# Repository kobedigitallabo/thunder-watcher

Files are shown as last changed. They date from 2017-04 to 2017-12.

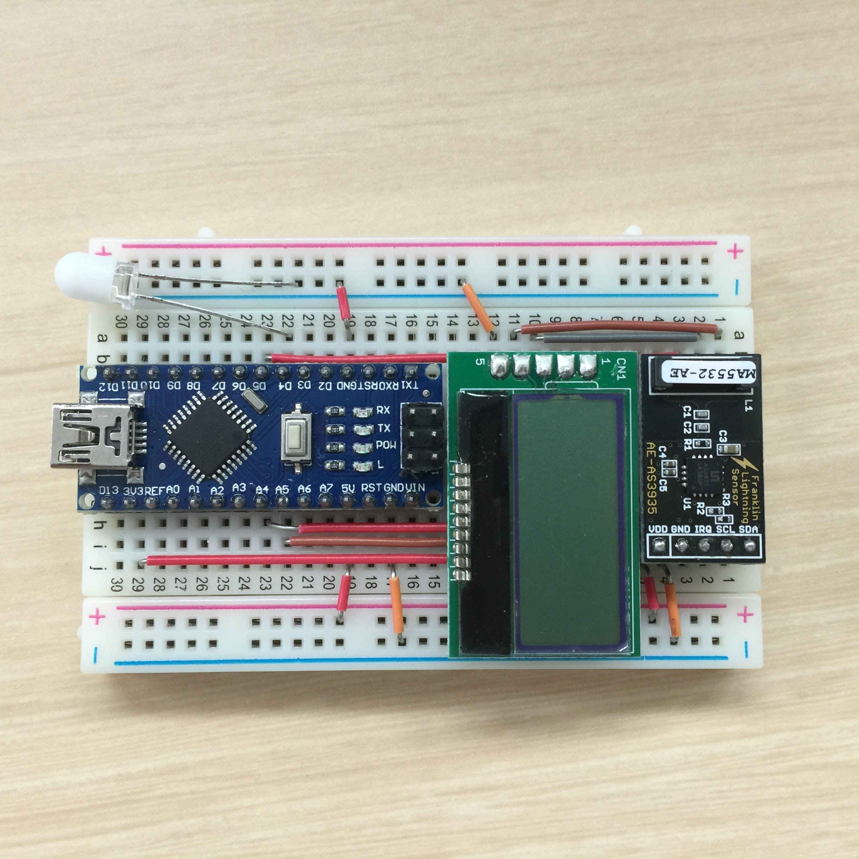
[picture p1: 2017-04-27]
document/protoboard2.jpg

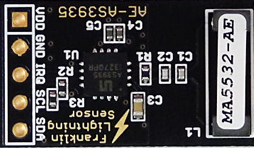
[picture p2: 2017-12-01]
document/AS3935.png

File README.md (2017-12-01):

The Thunder Watcher.
====
This device can sense the approach of lightning within several dozen kilometers, and make an alert to hide.
- Early warning indication of lightning storm activity within a 40km range.
- Provide you distance estimation from a overhead thunderstorm.
- Detects both cloud-to-ground and intra-cloud (cloud-to-cloud) flashes.
- The intelligent algorithm provides for false disturber rejection.

pic1.png (344.1 kB)

# Description
The Thunder Watcher  is a programmable Wearable Device that detects the presence and approach of potentially hazardous lightning activity in the vicinity.  
It detects intra-cloud activity as well as cloud to ground ashes, often enabling risk to be evaluated for approaching storms.   
The AS3935 IC detects lightning activity as it approaches from up to 40 km away, which provides a much longer distance for lightning warning.  

pic2.png (367.2 kB)

# Demo
ezgif.com-video-to-gif.gif (2.8 MB)

# Requirement
* [ Arduino IDE 1.6.13](https://www.arduino.cc/en/main/OldSoftwareReleases)
* [FreqCounter Library](http://interface.khm.de/index.php/lab/interfaces-advanced/arduino-frequency-counter-library/)
* [ST7032 Library](https://github.com/tomozh/arduino_ST7032)

# Usage
1. Turn on the power switch.(Initialization is started.) 
1. You have to wait for a thunderstorm. 
1. When a thundercloud is detected, the LED will light up.
And the distance to the thundercloud is displayed on the LCD display. 
1. If thunderclouds are near, evacuate to a safe place.

# What do we need
* [an Arduino nano board](https://www.amazon.com/HiLetgo-ATmega328P-Controller-Development-Unsoldered/dp/B01DLIJQA2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)

* [a Franklin Lightning Sensor (AS3935)](http://akizukidenshi.com/catalog/g/gK-08685/)

* [2x Round female pin header [5x1, 2.54mm]](https://www.amazon.com/Break-Away-Female-Headers-Machine/dp/B004G553U2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)
* 2x Male pin header [7x1, 2.54mm]
* [a  7x7 Perf Board  [2.54mm]](https://www.amazon.com/a14060500ux0490-Universal-Prototype-Solderable-Circuit/dp/B010XA3NZK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)
*  a 6x4  Perf Board  [2.54mm]
* [a Tinned Copper Wire](https://www.amazon.com/dp/B000IJU260/ref=biss_dp_t_asn)
* [a Plastic Battery Holder for 2 x 3V CR2032 Coin Button Cell](https://www.amazon.com/Copapa-Plastic-Battery-Holder-CR2032/dp/B01N0L9JFU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)
* Watch Bands
* an LED
* [an LED Lens, Diffused Beam](http://cy.rsdelivers.com/product/asahi-rubber/a-48068l-kc/asahi-rubber-a-48068l-kc-led-lens-diffused-beam/5017104)
* [a 150 Ohm Resistor, 1/4 W](https://www.amazon.com/E-Projects-100EP514150R-150-Resistors-Pack/dp/B0185FGNI4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)
* [an Empty electronic lighter](https://www.amazon.com/Refillable-Cigarette-Lighter-Flashlight-Quantity/dp/B009Z2R1U6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)

image.png (4.1 MB)

#  Tools You Need
* Soldering iron
* Soldering iron stand
* Solder
* Lead Nippers
* Needle Nose Pliers
* Reverse Action Tweezers
* Utility Knife
* Stainless Steel Ruler
* Glue gun

image.png (4.1 MB)

# The circuit
ThunderWatcher_circuit.png (492.4 kB)

# Install
## Importing a FreqCounter Library
[Lab3 \- Laboratory for Experimental Computer Science](http://interface.khm.de/index.php/lab/interfaces-advanced/arduino-frequency-counter-library/)

1. In the Arduino IDE, navigate to Sketch > Include Library. 
1. At the top of the drop down list, select the option to "Add .ZIP Library''.
1. You will be prompted to select the library you would like to add.
1. Return to the Sketch > Import Library menu. You should now see the library at the bottom of the drop-down menu.
1. It is ready to be used in your sketch. The zip file will have been expanded in the libraries folder in your Arduino sketches directory.

## Importing a ST7032 Library
[tomozh/arduino\_ST7032\- Arduino Liquid Crystal compatible library](https://github.com/tomozh/arduino_ST7032)

1. When you are on arduino_ST7032 project page, you press the 'Download ZIP' button which is located under the "Clone or Download" drop down.
1. This allows you to download the most recent version of the code as a zip archive.
image.png (23.1 kB)
1. Down list, select the option to "Add .ZIP Library''.
You will be prompted to select the library you would like to add.
1. Return to the Sketch > Import Library menu. You should now see the library at the bottom of the drop-down menu. 
1. It is ready to be used in your sketch. The zip file will have been expanded in the libraries folder in your Arduino sketches directory.

# How to make
More info is recorded in the "HowToMake-Desc.md" file.  
[HowTo/arduino/How to make  Thunder Watcher.](/HowToMake-Desc.md)

# Contribution
1. Fork it (http://github.com/kobedigitallabo/thunder-watcher )
2. Create your feature branch (git checkout -b my-new-feature)
3. Commit your changes (git commit -am 'Add some feature')
4. Push to the branch (git push origin my-new-feature)
5. Create a new Pull Request

# Licence
[MIT](/LICENSE.txt)

# Author
[kobedigitallabo](https://github.com/kobedigitallabo)

[haru-kdl](https://github.com/haru-kdl)

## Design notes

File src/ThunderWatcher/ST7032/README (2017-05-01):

ST7032 - Arduino LiquidCrystal compatible library
http://ore-kb.net/archives/195

-------------------------------------------------------------
 概要
-------------------------------------------------------------

コントローラに ST7032i を使った I2C LCD ディスプレイの
Arduino ライブラリです。
LiquidCrystal ライブラリのソースを元に作成しています。
LiquidCrystal ライブラリのメンバ関数と互換性があるため、
クラスを差し替えるだけで使用できます。

動作確認済み

    SB1602B             Strawberry Linux
    SB0802G             Strawberry Linux
    AQM0802A-RN-GBW     秋月電子通商

動作すると思われるもの

    SB1602E             Strawberry Linux
    LCD16X2-I2C         aitendo
    SPLC792-I2C-M       aitendo
    16X2-SPLC792-I2C    aitendo

-------------------------------------------------------------
 更新履歴
-------------------------------------------------------------

2014.10.13 コントラスト値のbit7がBONビットに影響する不具合を修正
2014.08.23 コンストラクタでI2Cアドレスを設定可能にした
2013.05.21 1st release

-------------------------------------------------------------
 ライセンス
-------------------------------------------------------------

作成者：
tomozh (tomozh@gmail.com)

ライセンス形態：
MIT

-------------------------------------------------------------
 使用方法
-------------------------------------------------------------

1) モジュールと Arduino を以下のように接続します

 ------------------------
  Arduino        ST7032
 ------------------------
  3.3V    --+-- VDD
            +-- -RES
  A4(SDA) --*-- SDA
  A5(SCL) --*-- SCL
  GND     ----- GND
  
  *... 10Kohm pull-up
 ------------------------

LCDを確実にリセットしたい場合は、RST 端子を Arduino の
空き端子で制御してください。(Low:リセット)
 
2) ST7032 フォルダを Arduino の libraries フォルダにコピーします

ST7032 独自のメンバ関数は以下の2種類です。

    コンストラクタ
       ST7032 lcd(int i2c_addr);
            i2c_addr: スレーブアドレス
            コンストラクタ引数を省略した場合は 0x3E

    コントラスト設定
        void setContrast(uint8_t cont)
            cont: コントラスト値 (0～63)
    
    アイコン表示 (※アイコン表示機能の無いLCDは無効)
        void setIcon(uint8_t addr, uint8_t bit)
            addr : アイコンアドレス (0～15)
            bit  : アイコン表示ビット (0x00～0x1F)

簡単な使い方

#include <Wire.h>
#include <ST7032.h>

ST7032 lcd;

lcd.setContrast(30);            // コントラスト設定
lcd.print("hello, world!");

スレーブアドレスを指定する場合

ST7032 lcd(0x3E);

-------------------------------------------------------------
 ファイル構成
-------------------------------------------------------------

ST7032\
    keywords.txt
    ST7032.cpp              ST7032 ライブラリ
    ST7032.h                ST7032 ライブラリ
    examples\
        Icon                Strawberry Linux SB1602B 用アイコン表示デモ
        Autoscroll          (*)
        Blink               (*)
        Cursor              (*)
        CustomCharacter     (*)
        Display             (*)
        HelloWorld          (*)
        Scroll              (*)
        SerialDisplay       (*)
        setCursor           (*)
        TextDirection       (*)

        (*)…LiquidCrystal liblary を ST032 用に改変

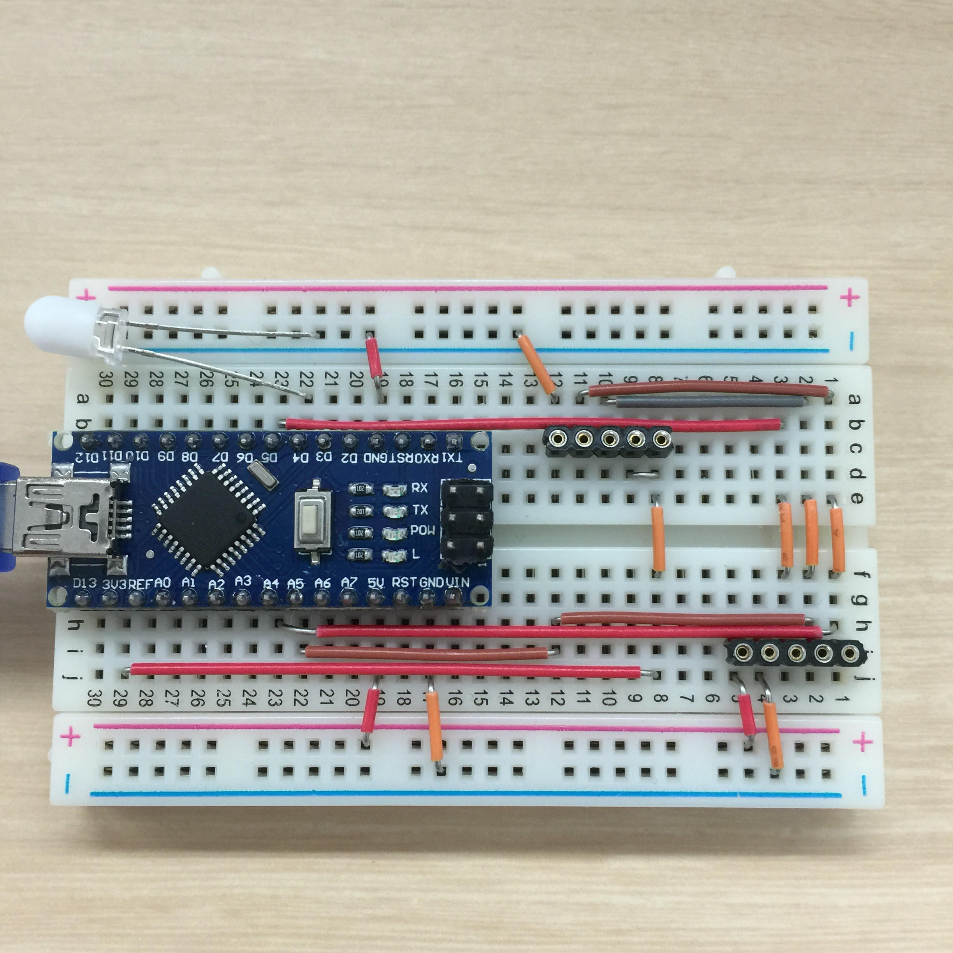
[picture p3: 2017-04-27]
document/protoboard1.jpg

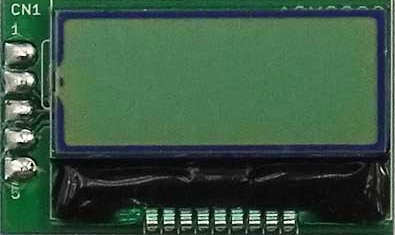
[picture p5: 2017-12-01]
document/AQM0802.png

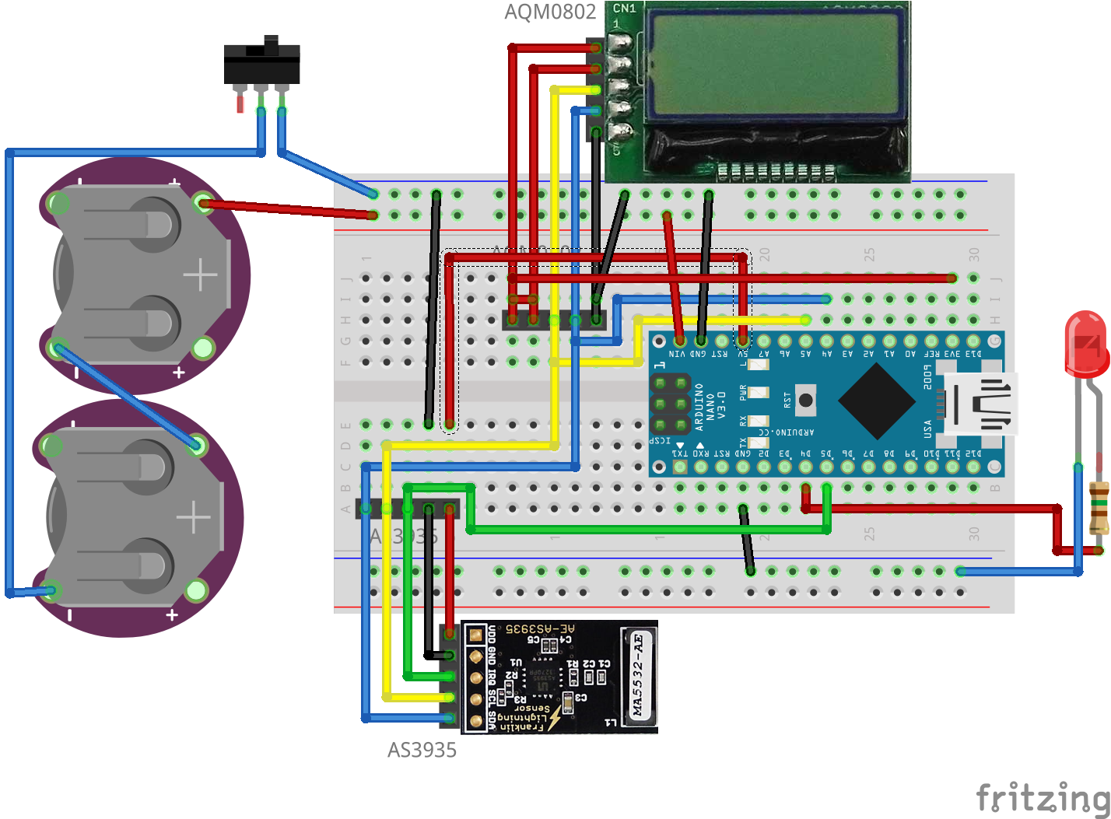
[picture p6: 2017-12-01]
document/ThunderWatcher_circuit.png

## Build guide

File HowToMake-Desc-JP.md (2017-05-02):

# Thunder Watcher 作成手順
## センサとLCDシールドを作成します。
まずは、センサとLCDシールドを作成します。

## ユニバーサル基板をカットする
2.54mm ピッチのユニバーサル基板をカットして、7x7 と 6x4  の板を準備します。  

スクリーンショット 2017-04-27 16.41.00.png (344.5 kB)

6x4 の基板は端の穴を半分残してカットします。

スクリーンショット 2017-04-27 16.42.33.png (225.3 kB)

## 7x7 穴のユニバーサル基板 にピンヘッダ(オス)を取り付ける
 
7x1  ピンヘッダ(オス) [2.54mm] を用意します。  
端子が長い側を銅パッド面となるように差し込みます。  
各ヘッダの一つのピンをはんだ付けします。  
これらのピンをはんだ付けした状態で、ヘッダの位置を確認してみてください。   
各ヘッダーは、基板に対して90°の角度となっている事が大切です。  
問題なければ残りのピンを全てはんだ付けします。 

スクリーンショット 2017-04-27 16.54.18.png (450.3 kB)

スクリーンショット 2017-04-27 16.55.30.png (292.4 kB)
スクリーンショット 2017-04-27 16.56.36.png (329.8 kB)

ピン番号は下図の通りです。
  
スクリーンショット 2017-04-27 16.56.36.png (329.8 kB)

## スズメッキ線をピンヘッダにはんだ付けする
スズメッキ線を14番ピンの近くの穴から通します。  
それを14番ピンにはんだ付けしてください。



基板を裏返し、下図の通りに折り曲げます。
余ったスズメッキ線は切断します。

image.png (121.2 kB)

下図の通りに折り曲げた場合、Arduinoのボタンと干渉してしまいますので、注意してください。

image.png (158.6 kB)

下図の通りに1番ピンにスズメッキ線をはんだ付けします。  

image.png (100.7 kB)

下図の通りに折り曲げます。

image.png (71.6 kB)

下図の通りに2番ピンにスズメッキ線をはんだ付けします。

image.png (90.6 kB)

下図の通りに折り曲げます。  

image.png (73.8 kB)

Pスズメッキ線を5番ピンの近くの穴から通します。  
それを5番ピンにはんだ付けしてください。  

png

png

下図の通りに折り曲げます。  
 
png

## 丸ピンヘッダ(メス)をはんだ付けする

7番ピンの近くの丸ピンヘッダ(メス)をはんだ付けします。  

Clip8.m4v 2017-04-27 17-49-46.png (84.8 kB)

裏返して、5番ピンからのびるスズメッキ線と丸ピンをはんだ付けします。  

Clip8.m4v 2017-04-27 17-52-48.png (72.0 kB)

 次に、14番ピンからのびるスズメッキ線と丸ピン(真ん中のピン)をはんだ付けします。  

Clip12.m4v 2017-04-27 20-52-08.png (347.5 kB)



1番ピンと2番ピンからのびるスズメッキ線と交差する丸ピン (右端とその隣) をはんだ付けします。





## 6x4 穴のユニバーサル基板にはんだ付けする
6x4 の基板を7x7 の基板に下図の通りにはんだ付けします。 
下図の通りに位置を合わせます。

 
下図の通りにはんだ付けします。  



1つのピンにハンダ付けします。  
高さの位置はピンヘッダの先頭に合わせてはんだ付けします。  
このピンをはんだ付けした状態で、ヘッダーの位置合わせをテストしてください。  


残りのピンも全てはんだ付けします。  



## 6x4の基板に丸ピンヘッダ(メス)をはんだ付けする

一番端のピンを下図の通りにはんだ付けします。  
Clip11.m4v 2017-04-27 18-24-50.png (103.6 kB)

下図の通りに、1番ピンをL字にスズメッキ線をはんだ付けします。  

Clip11.m4v 2017-04-27 18-28-19.png (349.8 kB)

下図の通りに、1番ピンからのびるスズメッキ線を、丸ピンヘッダまで折り曲げます。  

Clip11.m4v 2017-04-27 18-33-25.png (422.9 kB)

下図の通りに丸ピンヘッダにはんだ付けします。  
Clip11.m4v 2017-04-27 18-37-00.png (329.5 kB)

スズメッキ線を2番ピンの近くの穴から通します。
それを2番ピンにはんだ付けしてください。  
Clip11.m4v 2017-04-27 19-36-21.png (674.6 kB)

基板を裏返して、スズメッキ線を真ん中の丸ピンに触れるように折り曲げます。  

Clip11.m4v 2017-04-27 19-39-27.png (494.0 kB)

下図の通りに折り曲げます。  

Clip11.m4v 2017-04-27 19-41-06.png (345.7 kB)

下図の通りにはんだ付けします。  

Clip11.m4v 2017-04-27 19-45-35.png (449.4 kB)

残りの丸ピンヘッダも全てはんだ付けします。  
Clip11.m4v 2017-04-27 19-48-18.png (269.3 kB)

## GNDを接続する
スズメッキ線を下図の通りにはんだ付けします。  
Clip11.m4v 2017-04-27 19-51-44.png (269.3 kB)

下図の通りに折り曲げます。  

Clip11.m4v 2017-04-27 20-01-07.png (238.9 kB)

横からみた場合。  

Clip11.m4v 2017-04-27 19-57-52.png (351.9 kB)

横からみた場合。

Clip11.m4v 2017-04-27 19-54-59.png (573.5 kB)

下図の通りにはんだ付けします。（7番ピンにもはんだ付けをします。）  



横からみた場合。



真上からみた場合。  


## Vccを接続する
スズメッキ線を下図の通りにはんだ付けします。  
Clip12.m4v 2017-04-27 20-33-17.png (706.6 kB)

(2箇所のピンにはんだ付けしてください)
  
Clip12.m4v 2017-04-27 20-36-17.png (645.5 kB)

## Arduino nano を準備します。
Clip12.m4v 2017-04-27 20-38-15.png (1.1 MB)

シールドを下図の位置に差し込みます。  



 Arduino nano を下図の通りにはんだ付けします。  



3.3v ピンの方向にスズメッキ線を折り曲げます。  

Clip12.m4v 2017-04-27 21-06-29.png (1.1 MB)

横からみた場合。  

Clip12.m4v 2017-04-27 21-12-16.png (646.3 kB)

3.3Vピンにはんだ付けします。

Clip12.m4v 2017-04-27 21-14-07.png (677.6 kB)

## LEDを取り付ける
抵抗を折り曲げます。  



抵抗の端子を短く切断し10番ピンにはんだ付けします。

Clip13.m4v 2017-04-27 21-19-39.png (1.6 MB)

抵抗を折り曲げて短く切断します。

Clip13.m4v 2017-04-27 21-22-40.png (470.0 kB)

LEDに拡散キャップをとりつけます。
LEDの端子を短く切断します。
下図の通りに折り曲げます。
 


LEDを下図の通りにはんだ付けします。

Clip13.m4v 2017-04-27 21-29-10.png (847.6 kB)

LEDの端子を13番ピンに向けて折り曲げます。



下図の通りにはんだ付けします。

Clip13.m4v 2017-04-27 21-35-22.png (669.5 kB)

横からみた場合。

Clip13.m4v 2017-04-27 21-37-53.png (702.6 kB)

## 雷センサを組み立てます
雷センサにピンヘッダをはんだ付けします。  



端子を少しだけ短くカットします。

Clip13.m4v 2017-04-27 21-43-12.png (296.2 kB)

シールドに取り付けます。



## LCD ディスプレイの取り付け



シールドに取り付けます。 



## Arduinoへプログラムを書き込む
PCとArduinoを接続します。



ソースコードは以下よりダウンロードしておきます。
  
[kobedigitallabo/thunder\-watcher](https://github.com/kobedigitallabo/thunder-watcher)

Arduino IDEよりプログラムを書き込みます。
  


## 疑似雷発生装置の作成
 
空になった電子ライターとニッパーを準備します。  



ニッパーでライターの金属キャップを取り外します。  



これで完成です。

## 動作確認
正常に動作している事を確認します。
  


## 時計ベルトの取付
時計からベルトを取り外します。



スズメッキ線を使いArduinoとベルトを結びつけます。



反対側もベルトを取り付けます。
  


ラジオペンチで、スズメッキ線を結びます。



## バッテリーホルダーの取付
適切な長さにバッテリーホルダーのケーブルを切断します。



VINピンにプラス側のケーブルをはんだ付けします。
GNDピンにマイナス側のケーブルをはんだ付けします。 



グルーガンでバッテリーホルダーを接着します。



コイン電池をいれて、スイッチをオンにします。  


## 最終動作確認

正常に動作している事を確認します。



以上で完成です。
お疲れ様でした。

# ライセンス
[MIT](https://github.com/kobedigitallabo/thunder-watcher/blob/master/LICENSE.txt)

# 著者
[haru-kdl](https://github.com/haru-kdl)

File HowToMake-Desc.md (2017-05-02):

# How to make
## Create sensor and LCD shield.
First, Create sensor and LCD shield.

##  Cutting of the perfboard.
Cut the perfboard [2.54mm] into 7x7 holes and 6x4 holes.  
スクリーンショット 2017-04-27 16.41.00.png (344.5 kB)

Cut the 6x4 perfboard leaving half of the hole at the end.  
スクリーンショット 2017-04-27 16.42.33.png (225.3 kB)

## Solder Male pin header to 7x7 perfboard.
Prepare 7x1 Male pin header [2.54 mm].
Insert the long lead so that it becomes the copper pad surface.  
Solder one pin on each header.  
With those pins soldered, try to test the header's alignment.  
It's important that each of the headers is at a nice, 90° angle to the perfboard.  
Solder all remaining pins.  

スクリーンショット 2017-04-27 16.54.18.png (450.3 kB)

スクリーンショット 2017-04-27 16.55.30.png (292.4 kB)
スクリーンショット 2017-04-27 16.56.36.png (329.8 kB)

The pin number is as shown in the figure below.  
スクリーンショット 2017-04-27 16.56.36.png (329.8 kB)

## Solder tinned copper wire to pin header.  
Pass the tinned copper wire through the hole near the No. 14 pin. And, solder it to pin No. 14.



Turn the board over and bend it as shown in the figure below. 
And, cut the excess tinned copper wire.
image.png (121.2 kB)

Be careful, If you bend it as shown in the figure below, it interferes with Arduino buttons.
image.png (158.6 kB)

Solder the tinned copper wire to pin No.1 as shown in the figure below.  
image.png (100.7 kB)

Bend it as shown in the figure below.  
image.png (71.6 kB)

Solder the tinned copper wire to pin No.2 as shown in the figure below.  
image.png (90.6 kB)

Bend it as shown in the figure below.  
image.png (73.8 kB)

Pass the tinned copper wire through the hole near the No. 5 pin. And, solder it to pin No. 5.  
png

png

Bend it as shown in the figure below.  
png

## Solder to round female pin header.  
Solder the 5P round female pin header [2.54mm] near the No. 7 pin.  
Clip8.m4v 2017-04-27 17-49-46.png (84.8 kB)

Turn the board over and solder the tinned copper wire and round female pin header connected to pin No. 5.  
Clip8.m4v 2017-04-27 17-52-48.png (72.0 kB)

 Next, solder the tinned copper wire and round female pin header (in the middle)  connected to pin No. 14.  
Clip12.m4v 2017-04-27 20-52-08.png (347.5 kB)



Next, solder the tinned copper wire and round female pin header(The right end and its next pin) connected to pin No. 1 and pin No. 2.  




## Solder to 6x4 perfboard. 
Solder the 6x4 perfboard to  the 7x7 perfboard  as shown in the figure below.  

Adjust the position as shown below.  

 
Solder it as shown in the figure below.  


Solder to one pin.  
Solder the height position to the beginning of the pin header.  
With this pins soldered, try to test the header alignment.  


Solder all remaining pins.  


## Solder round female pin header to 6x4 perfboard. 
Solder to one round female pin header, it as shown in the figure below.  
Clip11.m4v 2017-04-27 18-24-50.png (103.6 kB)

As shown in the figure below, solder the tin plating wire to pin 1 in L shape.  
Clip11.m4v 2017-04-27 18-28-19.png (349.8 kB)

Solder the tinned copper wire and round female pin header connected to pin No. 1 as shown in the figure below.  
Clip11.m4v 2017-04-27 18-33-25.png (422.9 kB)

Solder to the round female pin header, it as shown in the figure below.  
Clip11.m4v 2017-04-27 18-37-00.png (329.5 kB)

Pass the tinned copper wire through the hole near the No. 2 pin.
And, solder it to pin No. 2.  
Clip11.m4v 2017-04-27 19-36-21.png (674.6 kB)

Turn the board over and bend the tinned copper wire so that it touches  (of the middle) round pin.  
Clip11.m4v 2017-04-27 19-39-27.png (494.0 kB)

Bend it as shown in the figure below.  
Clip11.m4v 2017-04-27 19-41-06.png (345.7 kB)

Solder it as shown in the figure below.  
Clip11.m4v 2017-04-27 19-45-35.png (449.4 kB)

Solder all remaining pin. (Round female pin header.)  
Clip11.m4v 2017-04-27 19-48-18.png (269.3 kB)

## Connecting GND.
Solder the tinned copper wire as shown in the figure below.  
Clip11.m4v 2017-04-27 19-51-44.png (269.3 kB)

Bend it as shown in the figure below.  
Clip11.m4v 2017-04-27 20-01-07.png (238.9 kB)

View from the side.  
Clip11.m4v 2017-04-27 19-57-52.png (351.9 kB)

View from the side.  
Clip11.m4v 2017-04-27 19-54-59.png (573.5 kB)

Solder it as shown in the figure below. (And, solder the pin No. 7.)  


View from the side.  


View from directly above.  


## Connecting Vcc.  
Solder the tinned copper wire as shown in the figure below.  
Clip12.m4v 2017-04-27 20-33-17.png (706.6 kB)

(Solder the pin to two places.)  
Clip12.m4v 2017-04-27 20-36-17.png (645.5 kB)

## Prepare Arduino nano.
Clip12.m4v 2017-04-27 20-38-15.png (1.1 MB)

Insert the shield in the position shown in the figure below.  


Solder to Arduino nano as shown in the figure below.  


Bend the tinned copper wire in the 3.3V pin direction.  
Clip12.m4v 2017-04-27 21-06-29.png (1.1 MB)

View from the side.  
Clip12.m4v 2017-04-27 21-12-16.png (646.3 kB)

Solder to the 3.3V pin.  
Clip12.m4v 2017-04-27 21-14-07.png (677.6 kB)

## Connecting LED.
Bend the resistor.  


Cut the resistor lead short and solder the lead to pin No. 10.  
Clip13.m4v 2017-04-27 21-19-39.png (1.6 MB)

Bend the resistance and about cut short.  
Clip13.m4v 2017-04-27 21-22-40.png (470.0 kB)

Attach a diffused beam cover to the LED.  
Short cut the LED lead.  
Bend it as shown in the figure below.  


Solder the LED as shown in the figure below.  
Clip13.m4v 2017-04-27 21-29-10.png (847.6 kB)

Bend the LED lead in the No. 13 pin direction.  


Solder it as shown in the figure below.  
Clip13.m4v 2017-04-27 21-35-22.png (669.5 kB)

View from the side.  
Clip13.m4v 2017-04-27 21-37-53.png (702.6 kB)

## Assemble the lightning sensor.  
Solder the pin header to the lightning sensor.  


Cut the lead a little bit shorter.  
Clip13.m4v 2017-04-27 21-43-12.png (296.2 kB)

Plug it into the shield.  


## Attach LCD display.  


Plug it into the shield.  


## Write the program to the Arduino. 
Connect PC to the Arduino.  


Download the source code from below.  
[kobedigitallabo/thunder\-watcher](https://github.com/kobedigitallabo/thunder-watcher)

Write the program from Arduino IDE.  


## Creation of pseudo lightning generator.
 
Prepare an Empty electronic lighter and needle nose pliers.  


Remove the lighter metal cap with the needle nose pliers.  


To complete a pseudo lightning generator.  

## Test. 
Confirm that it normally.  


## Attach watch belt.  
Remove the belt from the watch.  


Use the tinned copper wire to tie Arduino and watch belt.  


Also install the watch belt on the other side.  


Tie the tinned copper wire with the needle nose pliers.  


## Attach battery holder. 
Cut the battery holder cable to the appropriate length.  


Solder the positive side cable to the VIN pin.  
Solder the minus side cable to the GND pin.  


Glue the battery holder with glue gun.  


Insert the coin battery and turn on the switch.  


## Final testing.  
Confirm that it normally.  


All is completed with this.  
Have a nice prototyping.  

# Licence
[MIT](https://github.com/kobedigitallabo/thunder-watcher/blob/master/LICENSE.txt)

# Author
[haru-kdl](https://github.com/haru-kdl)

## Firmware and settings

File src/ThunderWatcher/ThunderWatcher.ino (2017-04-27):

//AS3935 SCL = A5
//AS3935 SDA = A4
//AS3935 IRQ = D5
//AQM1602 SCL = A5
//AQM1602 SDA = A4
//USE 5V PWR

#include <ST7032.h> // LCD library
#include <Wire.h>
#include <FreqCounter.h>

#define AS3935_ADRS 0x00
#define LCD_ADRS 0x3E 

#define AFE_GB  0x1F  // ANALOG FRONT END GAIN BOOST = 12(Indoor) 0x00 to 0x1F
#define NF_LEV  0x02  // NOIS FLOOR LEVEL 0x00 to 0x07
#define WDTH    0x02  // WATCH DOG THRESHOLD 0x00 to 0x0F

ST7032 lcd;

String LCD_STRING;
byte reg0,reg1,reg2,reg3,reg4,reg5,reg6,reg7,reg8,reg3A,reg3B,reg3C,reg3D,regDUMMY;
unsigned long enargy;
unsigned int distance;
long int freq;
long int OLD_BUFFER = 10000;
long int NOW_BUFFER = 0;
int C;
long int F;
byte CAP_RESULT;

// Thunder mark character
byte Lightning[8] = {
	0b00010,
	0b00100,
	0b01100,
	0b11111,
	0b00110,
	0b00100,
	0b01000,
	0b10000
};

void ByteWrite(byte reg, byte data)
{
  Wire.beginTransmission(AS3935_ADRS);
  Wire.write(reg);
  Wire.write(data);
  Wire.endTransmission();
  delay(50);
}

byte ByteRead(byte reg)
{
  byte data = 0;
  Wire.beginTransmission(AS3935_ADRS);
  Wire.write(reg);
  Wire.endTransmission(false);
  Wire.requestFrom(AS3935_ADRS,1);
  data = Wire.read();      // Receive 1 byte
  return data;
}

void resistorRead(void)
{
  Wire.beginTransmission(AS3935_ADRS);
  Wire.write(0);
  Wire.endTransmission(false);
  Wire.requestFrom(AS3935_ADRS,9);
  reg0 = Wire.read();
  reg1 = Wire.read();
  reg2 = Wire.read();
  reg3 = Wire.read();
  reg4 = Wire.read();
  reg5 = Wire.read();
  reg6 = Wire.read();
  reg7 = Wire.read();
  reg8 = Wire.read();
  Wire.beginTransmission(AS3935_ADRS);
  Wire.write(0x3A);
  Wire.endTransmission(false);
  Wire.requestFrom(AS3935_ADRS,4);
  reg3A = Wire.read();
  reg3B = Wire.read();
  reg3C = Wire.read();
  reg3D = Wire.read();
  
}

void setup()
{
  pinMode(2,INPUT);
  
  Wire.begin();
  Serial.begin(9600);          // start serial communication at 9600bps
  Serial.println("READY");   // print the reading
  // create a new character
  lcd.createChar(5, Lightning);
  
  INIT_LCD();
  DISP_OPENNING();
  INIT_AS3935();
}

void loop()
{
  writeCommand(0x01); // Clear Display  
  while(1)
  {
  if (digitalRead(5)== HIGH) INT_DETECTS(); 
  }
}

void INT_DETECTS(void)
{
  digitalWrite(4, HIGH);  // LED ON
  byte reg3buffer;
  delay(4);
  resistorRead();
  reg3buffer = reg3 & 0x0F;
  if (reg3buffer == 0x01) INT_NH();
  if (reg3buffer == 0x04) INT_D();
  if (reg3buffer == 0x08) INT_L();
  digitalWrite(4, LOW);  // LED OFF
}

void INT_NH(void)  //noise level too high
{
  writeCommand(0x01); // Clear Display  
  LCD_STRING = "Nois Level High ";
  LCD_DISP_16_1();
  LCD_STRING = "el High ";
  LCD_DISP_16_2();
  delay(700);
  writeCommand(0x01); // Clear Display  
  LCD_STRING = "Watching........ ";
  LCD_DISP_16_1();
}

void INT_D(void)  //disturber detected
{
  writeCommand(0x01); // Clear Display  
  LCD_STRING = "Disturbe";
  LCD_DISP_16_1();
  LCD_STRING = "r DETect";
  LCD_DISP_16_2();
  delay(1500);
  writeCommand(0x01); // Clear Display  
  LCD_STRING = "Watching........";
  LCD_DISP_16_1();
}

void INT_L(void)  //lightning interrupt
{
  writeCommand(0x01); // Clear Display  
  enargy = (((reg6 & 0x0F) * 65536)+ (reg5 * 256)+ (reg4)) & 0x0FFFFF;
  distance = (reg7 );
  lcd.setCursor(0, 0);
  lcd.write(5);
  LCD_STRING = "E=" + String(enargy) ;
  lcd.setCursor(1, 0);
  LCD_DISP_16_1();
  LCD_STRING = "D=" + String(distance) + "km";

  if(reg7 == 0x01)  LCD_STRING = "E=" + String(enargy) + " OvrHed";
  if(reg7 == 0x3F)  LCD_STRING = "E=" + String(enargy) + " OutRng";
  LCD_DISP_16_2();
  serialDisplay();
  delay(5000);
  writeCommand(0x01); // Clear Display  
  LCD_STRING = "Watching........";
  LCD_DISP_16_1();
}

void INIT_AS3935(void)
{
  ByteWrite(0x3C,0x96);
  ByteWrite(0x3D,0x96);
  ByteWrite(0x00,(AFE_GB << 1));  // SET ANALOG FRONT END GAIN BOOST
  ByteWrite(0x01,((NF_LEV << 4) | WDTH));
  ByteWrite(0x03,0x00);           // FRQ DIV RATIO = 1/16
  CALIB_LCO();
}

void CALIB_LCO(void)
{
  writeCommand(0x01); // Clear Display  
  delay(20);
  LCD_STRING = "NOW CALIBRATION ";
  LCD_DISP_16_1();
  LCD_STRING = "C=000pF F=500000";
  LCD_DISP_16_2();
  FREQ_COUNT();    //DUMMY
  for ( byte b = 0; b < 0x10 ; b++)
  {
    ByteWrite(0x08,(0x80 | b));
    delay(50);
    FREQ_COUNT();
    NOW_BUFFER = abs(freq - 3125);
    if(OLD_BUFFER > NOW_BUFFER) CAP_RESULT = b;
    OLD_BUFFER = NOW_BUFFER;
    Serial.print("CAP = ");
    Serial.print(b,DEC);
    Serial.print(" freq = ");
    Serial.println((freq * 16 * 10 ),DEC );
    LCD_STRING = String(b * 8);
    writeCommand(0x40+0x82);
    for(int i = 0; i < 3; i++)
    {
      writeData(LCD_STRING[i]);
    }
    LCD_STRING = String(freq * 16 * 10);
    writeCommand(0x40+0x8A);
    for(int i = 0; i < 7 ; i++)
    {
      writeData(LCD_STRING[i]);
    }
    delay(300);
  }
  writeCommand(0x01); // Clear Display 
  Serial.print("CAP_RESULT=");
  Serial.print(CAP_RESULT);
  Serial.print("   ");
  Serial.print(CAP_RESULT * 8);
  Serial.println("pF");
  ByteWrite(0x08,(0x80 | CAP_RESULT));
  delay(100);
  FREQ_COUNT();
  LCD_STRING = "CALIBRATION DONE";
  LCD_DISP_16_1();
  LCD_STRING = "pF 5000000Hz    ";
  LCD_DISP_16_2();
  LCD_STRING = String(CAP_RESULT * 8); 
  writeCommand(0x40+0x80);
  for (int i = 0; i < 3; i++)
  {
    writeData(LCD_STRING[i]);
  }
  LCD_STRING = String(freq * 16 * 10);
  writeCommand(0x40+0x87);
  for (int i = 0; i < 7; i++)
  {
    writeData(LCD_STRING[i]);
  }
  ByteWrite(0x08,CAP_RESULT);
  delay(3000);
}

void  FREQ_COUNT(void)
{
    FreqCounter::f_comp = 10;
    FreqCounter::start(100);
    while (FreqCounter::f_ready == 0);
    freq = FreqCounter::f_freq;
}  

void DISP_OPENNING(void)
{
  LCD_STRING = "Lightning Sensor";
  LCD_DISP_16_1();
  writeCommand(0x40+0x80);
  LCD_STRING = "   AS3935 DEMO  ";
  LCD_DISP_16_2();
  delay(2000);
}
  
//Write Data
void writeData(byte t_data)
{
  Wire.beginTransmission(LCD_ADRS);
  Wire.write(0x40);
  Wire.write(t_data);
  Wire.endTransmission();
delay(1);
}
//Write Command
void writeCommand(byte t_command)
{
  Wire.beginTransmission(LCD_ADRS);
  Wire.write(0x00);
  Wire.write(t_command);
  Wire.endTransmission();
delay(10);
}

//Initialize LCD
void INIT_LCD() 
{
    lcd.begin(8, 2);      // LCD range
    lcd.setContrast(30);  // Contrast setting 
    lcd.setCursor(0, 0);  // Cursor position
}

void LCD_DISP_16_1(void)
{
  for(int i = 0; i < 16; i++)
  {
    writeData(LCD_STRING[i]);
  }
}

void LCD_DISP_16_2(void)
{
  writeCommand(0x40+0x80);
  for(int i = 0; i < 16; i++)
  {
    writeData(LCD_STRING[i]);
  }
}


void serialDisplay(void)
{
  Serial.print(LCD_STRING); 
  Serial.print(" reg0=");
  Serial.print(reg0,HEX);
  Serial.print(" reg1=");
  Serial.print(reg1,HEX);
  Serial.print(" reg2=");
  Serial.print(reg2,HEX);
  Serial.print(" reg3=");
  Serial.print(reg3,HEX);
  Serial.print(" reg4=");
  Serial.print(reg4,HEX);
  Serial.print(" reg5=");
  Serial.print(reg5,HEX);
  Serial.print(" reg6=");
  Serial.print(reg6,HEX);
  Serial.print(" reg7=");
  Serial.print(reg7,HEX);
  Serial.print(" reg8=");
  Serial.println(reg8,HEX);
}

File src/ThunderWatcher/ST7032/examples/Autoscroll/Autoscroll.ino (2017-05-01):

/*
	ST7032 I2C LCD control sample
	Original source : Autoscroll.ino (LiquidCrystal Library)
	2013/05/21 tomozh@gmail.com
*/

/*
  LiquidCrystal Library - Autoscroll
 
 Demonstrates the use a 16x2 LCD display.  The LiquidCrystal
 library works with all LCD displays that are compatible with the 
 Hitachi HD44780 driver. There are many of them out there, and you
 can usually tell them by the 16-pin interface.
 
 This sketch demonstrates the use of the autoscroll()
 and noAutoscroll() functions to make new text scroll or not.
 
 The circuit:
 * LCD RS pin to digital pin 12
 * LCD Enable pin to digital pin 11
 * LCD D4 pin to digital pin 5
 * LCD D5 pin to digital pin 4
 * LCD D6 pin to digital pin 3
 * LCD D7 pin to digital pin 2
 * LCD R/W pin to ground
 * 10K resistor:
 * ends to +5V and ground
 * wiper to LCD VO pin (pin 3)
 
 Library originally added 18 Apr 2008
 by David A. Mellis
 library modified 5 Jul 2009
 by Limor Fried (http://www.ladyada.net)
 example added 9 Jul 2009
 by Tom Igoe 
 modified 22 Nov 2010
 by Tom Igoe
 
 This example code is in the public domain.

 http://arduino.cc/en/Tutorial/LiquidCrystalAutoscroll

 */

// include the library code:
//#include <LiquidCrystal.h>
#include <Wire.h>
#include <ST7032.h>

// initialize the library with the numbers of the interface pins
//LiquidCrystal lcd(12, 11, 5, 4, 3, 2);
ST7032 lcd;

void setup() {
  // set up the LCD's number of columns and rows: 
  lcd.begin(16,2);
  lcd.setContrast(30);
}

void loop() {
  // set the cursor to (0,0):
  lcd.setCursor(0, 0);
  // print from 0 to 9:
  for (int thisChar = 0; thisChar < 10; thisChar++) {
   lcd.print(thisChar);
   delay(500);
  }

  // set the cursor to (16,1):
  lcd.setCursor(16,1);
  // set the display to automatically scroll:
  lcd.autoscroll();
  // print from 0 to 9:
  for (int thisChar = 0; thisChar < 10; thisChar++) {
    lcd.print(thisChar);
    delay(500);
  }
  // turn off automatic scrolling
  lcd.noAutoscroll();
  
  // clear screen for the next loop:
  lcd.clear();
}

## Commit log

2017-04-27 create circuit document
    [ThunderWatcher.fzz]
2017-05-02 create 策定手順書
2017-05-02 作成手順書
2017-05-02 日本語版手順書
2017-12-01 fixed circuit map. add AQM0802 and AS3935 images.
    [ThunderWatcher.fzz]
